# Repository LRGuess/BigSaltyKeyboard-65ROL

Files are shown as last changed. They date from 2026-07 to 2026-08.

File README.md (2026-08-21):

# BigSaltyKeyboard-65ROL
A 65% Keyboard with a rotary encoder, OLED screen and LEDs

## BOM:

- 1x Raspberry Pi Pico
- 68x Cheery MX Switches and their keycaps
- 68x [1N4148 Through-Hole Diodes](https://www.digikey.ca/en/products/detail/onsemi/1N4148/458603)
- 1x 6.25u Stabilizer
- 2x 2.25u Stabilizer
- 1x 2u Stabilizer
- 68x [SK6812 MINI-E LEDs](https://www.lcsc.com/product-detail/C5149201.html)
- 1x [Logic Level Shifter](https://www.digikey.ca/en/products/detail/texas-instruments/SN74AHCT1G125DBVR/376028)
- 69x [0.1 µF Chip Capacitor](https://www.digikey.ca/en/products/detail/samsung-electro-mechanics/CL05B104KP5VPNC/20498482)
- 1x [500 OHM Chip Resistor](https://www.digikey.ca/en/products/detail/yageo/RT0603BRC07500RL/7708292)
- 2x [10 Pin Horizontal Header](https://www.digikey.ca/en/products/detail/w%C3%BCrth-elektronik/61301011021/2508443)

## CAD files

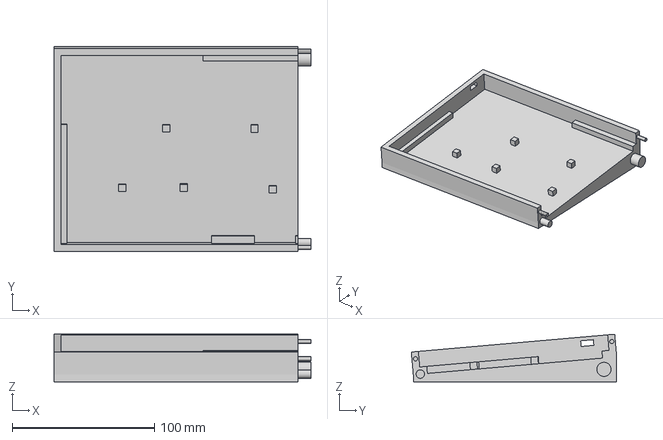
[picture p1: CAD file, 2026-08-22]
Case/CaseLeft.3mf
180.9 x 144.6 x 33.5 mm

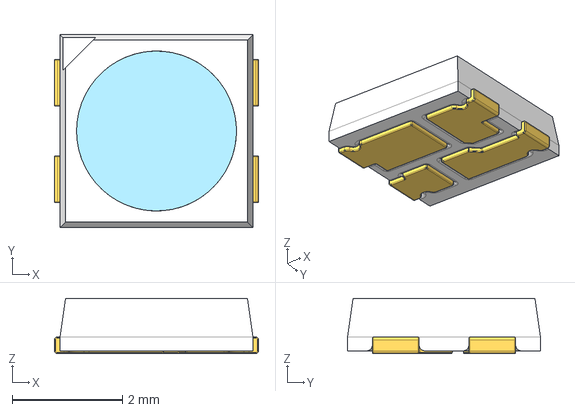
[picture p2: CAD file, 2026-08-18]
PCB/KeyboardPCB/Assets/3D Models/WS2812B Mini.stp
3.70 x 3.50 x 1.00 mm

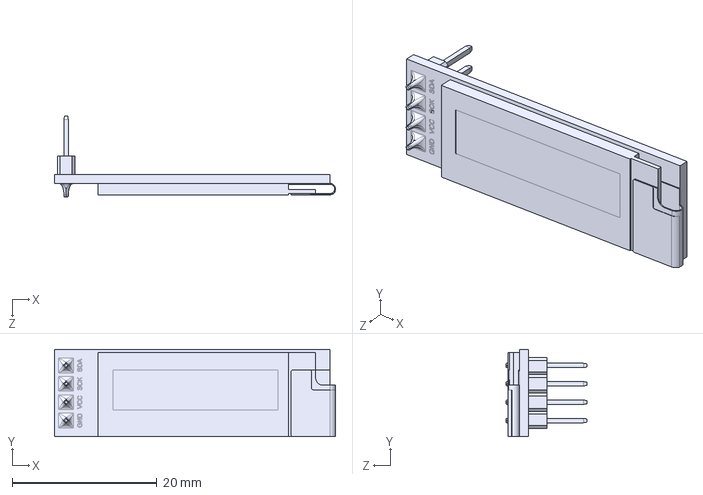
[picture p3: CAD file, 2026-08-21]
PCB/RearExtensionPCB/Assets/3D Models/OLED Screen.STEP
38.8 x 12.1 x 11.2 mm

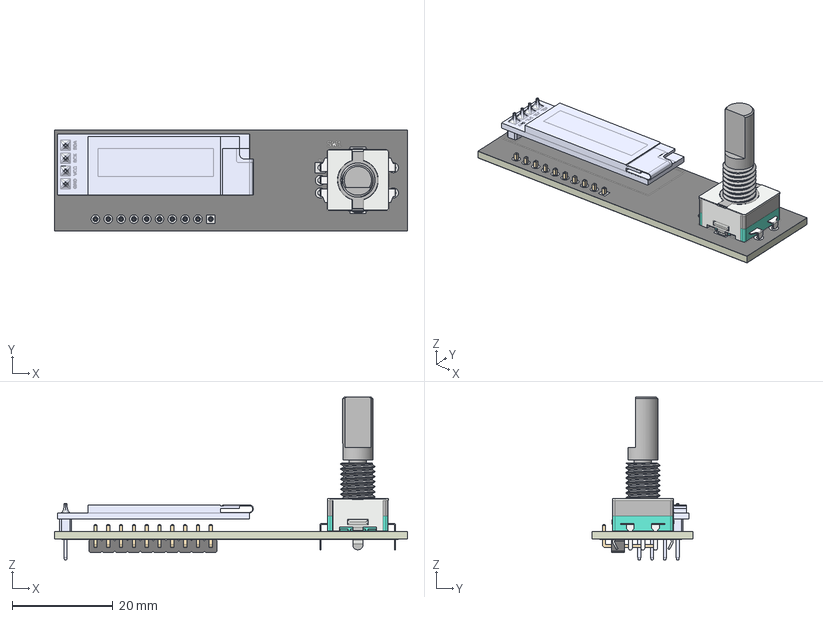
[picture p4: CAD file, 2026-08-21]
PCB/RearExtensionPCB/RearExtensionPCB.step
70.0 x 20.0 x 32.3 mm
EC11 v3
0.91in OLED
PinHeader_1x10_P254mm_Horizontal
RearExtensionPCB_copper
RearExtensionPCB_pad
RearExtensionPCB_via
RearExtensionPCB_silkscreen x 2
RearExtensionPCB_soldermask x 2
RearExtensionPCB_PCB

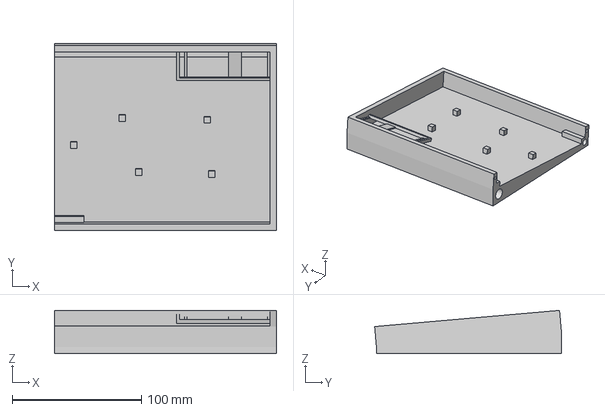
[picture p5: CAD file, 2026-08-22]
Case/CaseRight.3mf
171.9 x 144.6 x 33.5 mm

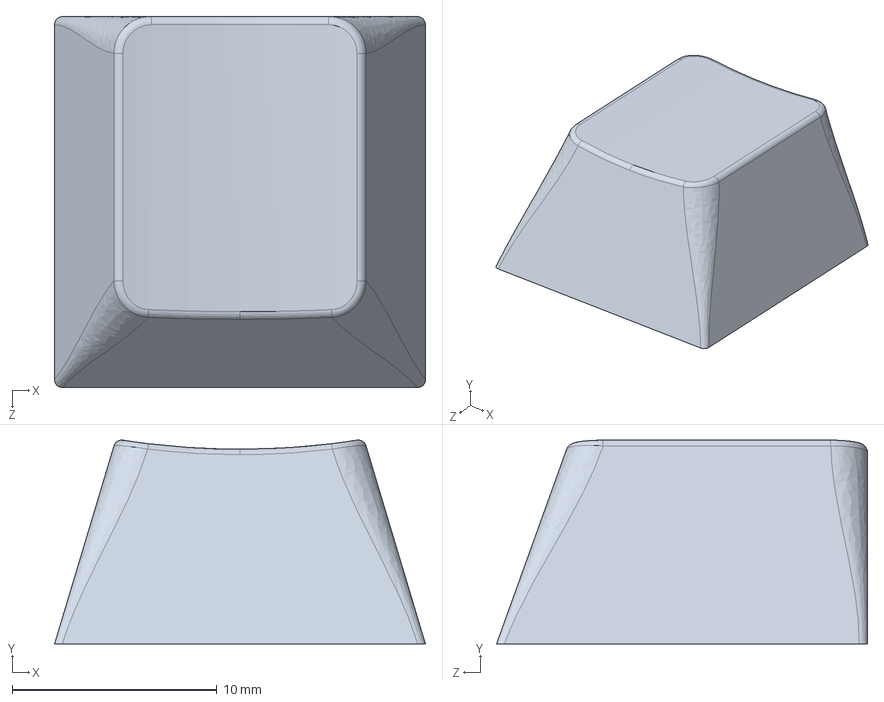
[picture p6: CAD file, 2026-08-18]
PCB/KeyboardPCB/Assets/3D Models/Keycap.STEP
18.1 x 9.95 x 18.1 mm

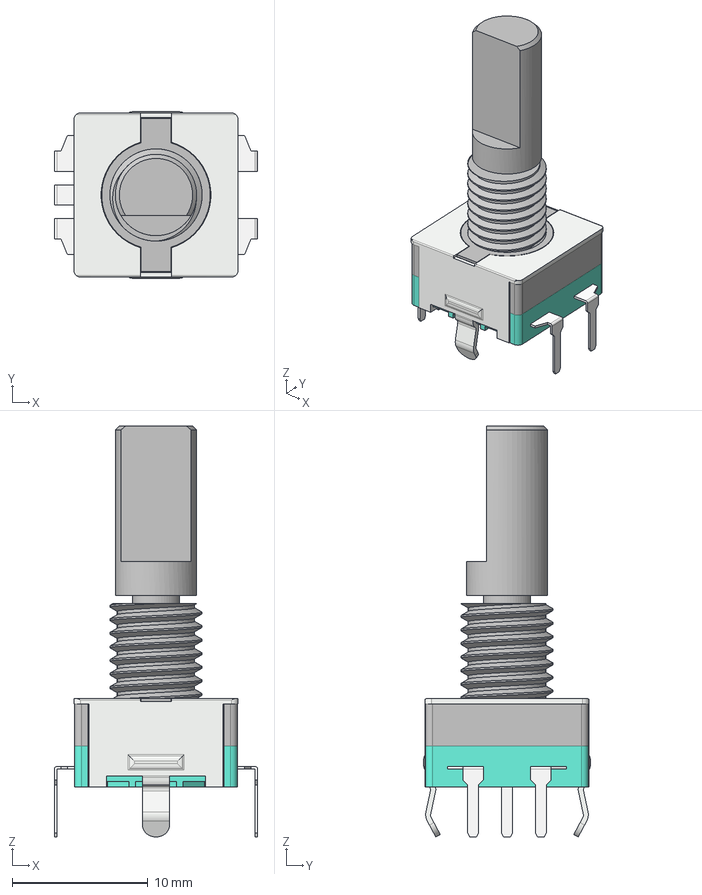
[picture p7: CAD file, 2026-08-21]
PCB/RearExtensionPCB/Assets/3D Models/Rotary Encoder.step
15.0 x 12.3 x 30.3 mm

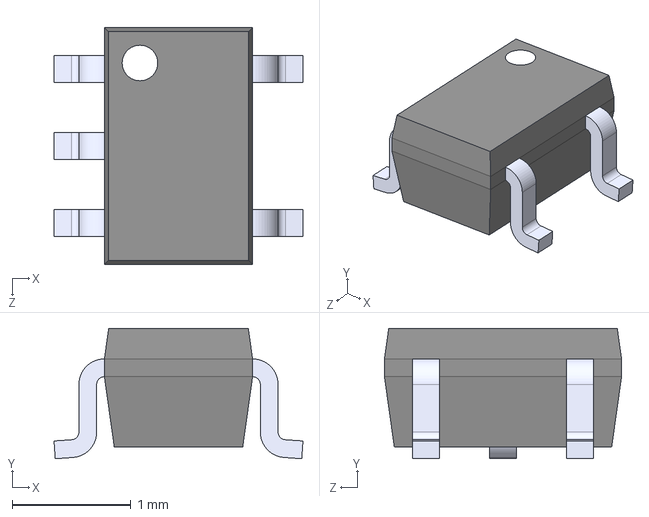
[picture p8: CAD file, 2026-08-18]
PCB/KeyboardPCB/Assets/3D Models/SN74AHCT1G125DCKT.step
2.10 x 1.10 x 2.00 mm

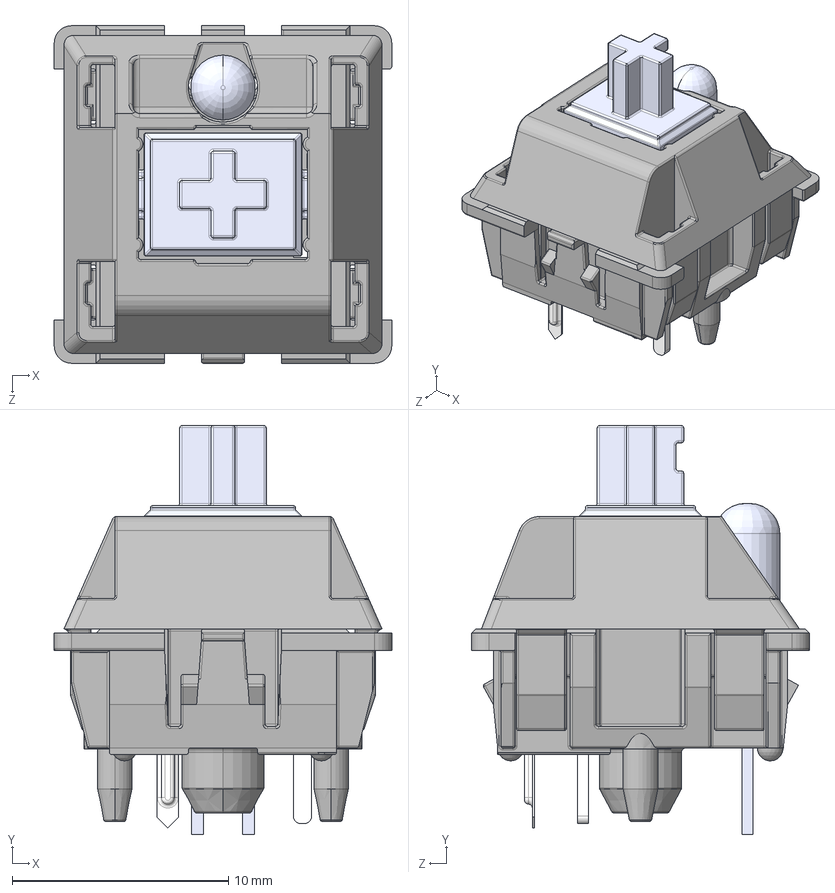
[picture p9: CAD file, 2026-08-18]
PCB/KeyboardPCB/Assets/3D Models/MX_Switch.STEP
15.6 x 18.9 x 15.6 mm
MX 轴 按键′_ü___¨1
MX 轴 轴体áì_¨￠¨__
MX粣 拸簽LEDLEDLED
MX轴 轴体 底部 μ×2__默认_á2____è_
针脚___默认__è_

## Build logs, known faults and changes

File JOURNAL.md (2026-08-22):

## Journal
You can visit the `./Photos` folder to find pictures related to each devlog!  
### Jul 25, Devlog 1: 3 hours
Behold, the start of the project!
I do not have much experiance making keyboards but have been thinking of building one for a lil bit now, and once I came across Keeb it seemed like a great opportunity!  
I kicked this project off with a bit of planning and I present to you the overview of my custom keyboard:  
- Main Board:  
The BigSaltyKeyboard will be a 65% keyboard, meaning it will contain the primary keys + the 4 arrow keys + 4 nav keys: Del, Ins, Pup, and Pdn. I chose this layout as I really enjoy the smallness of 60%s but I certain games I play require the use of the arrows and being able to use the nav keys really helps typing flow. 
The keys will also be a bit offset from each other in the standard way most keyboards do simply for the ergonomics.

- Extra Spice:  
My keyboard will have a few hardware and software features that bring it's uniquness to life! First of all every key will have an SK6812 Mini-E LED under it to add some flare and animations! The top of the keybaord will have a small panel extending upwards containing some cool extra features, mainly a 0.91in programmable OLED screen and a rotary encoder that will be dedicated to volume control! It will also contain some small buttons that can br programmed to do whatever you please!

PCB Design:  
I begun the project by starting the schematic for the PCB in KiCad! For now all I have are ~68 keys connected to diodes for the key matrix and labeled onto the Pico! Due to the nature of the project it will need 2 PCB's, one for the board and another for the extended top, but for now ill work only on the board. 

Next Up:
1. Link footprints and but together PCB with keys
2. LEDs

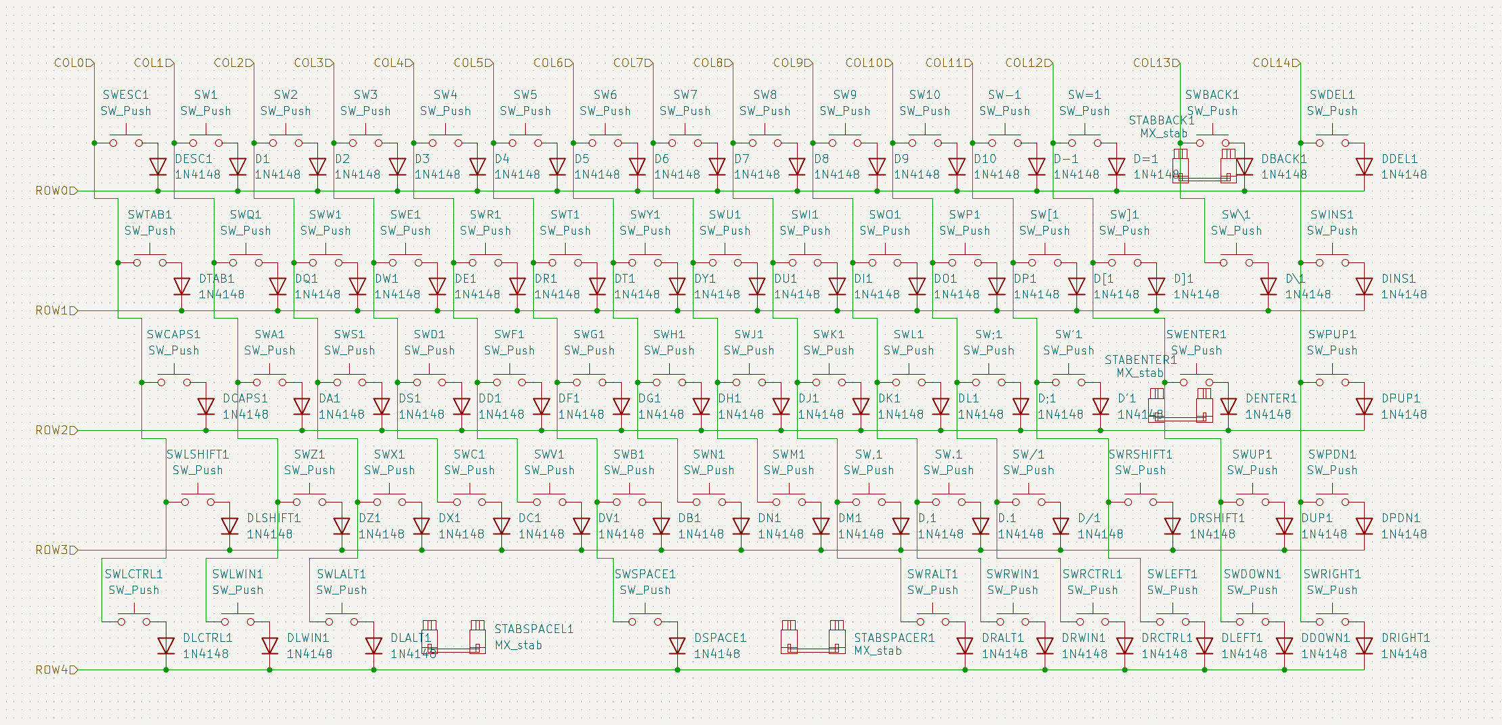
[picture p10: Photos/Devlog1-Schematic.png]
Devlog1 Image
 

### Jul 26, Devlog 2: 3 hours
After having finished the key's schematic layout for the base PCB I dedcided the next step was to lay the keys out on the PCB! My current keyboard is an ATK RS6, and I'm quite used to it's layout and spacing so I decided I would replicate it with a small tweak: I made the left control key just a little bit larger so that I don't have to extend my thumb as far as I do on my current one. Honestly, spacing the keys out was kinda hard but it was a great learning opportunity, and figuring out how to place the stabalizers was also fun to figure out.  
Something I did to help figure the proper spacing out was downloading the CAD for an MX key and a keycap for the switch footprint so I could visualize the spacing in the 3D tool! At first I got the switch CAD to import no problem, but as soon as I tried to import the keycap it wouldn't show up. Long story short, for some ungodly reason KiCAD didn't like the keycap's CAD to be in an STL format but after a conversion to STP everything went smoothly. 

Next Up:
1. Place diodes, Pico, and define board edge.
2. LEDs

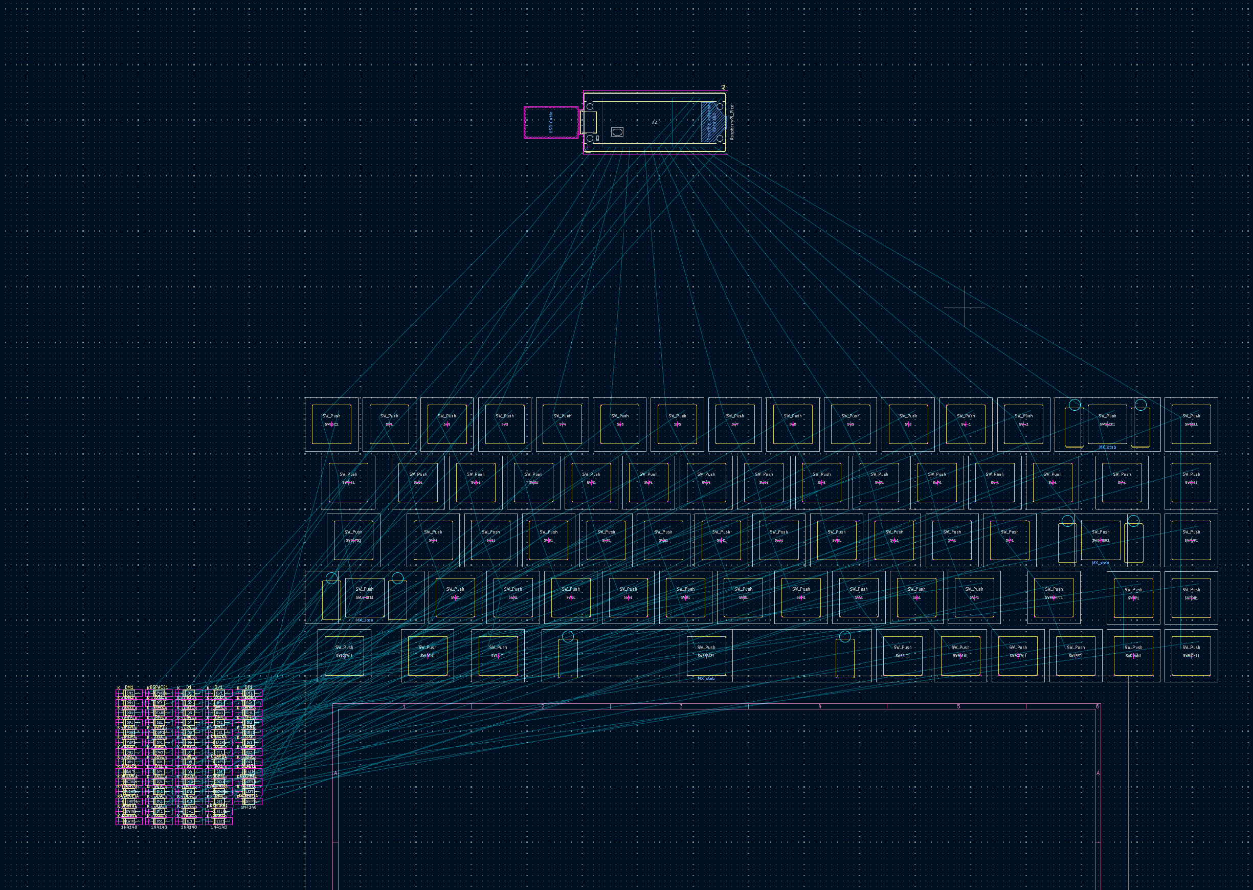
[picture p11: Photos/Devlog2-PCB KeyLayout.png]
Devlog2 Image
 

### Jul 26, Devlog 3: 4 hours
Right off the bat this part took a lot longer than I thought it would. Manually trying to drag every single diode to the right position was an absolute nightmare they're so small it's literally aim trainging of some sorts. Holy cow. 
Anyways, after placing every diode I decided to place the Pico right above the entire structure. Yes this adds a lot of space but that space will be right under the extention and I do need a spot to place the connectors to the other PDB. I'll get into that more in the next devlog.
The last thing I did was define the board's outlines and add a ground fill. I'm leaving about 2.4mm of space between the edge of the board and the switches, which I think will be enough for a sandwitch fit case. Running the DRC nothing failed so all is well with the board for now!

Next Up:
1. LEDs
2. Plan 2nd board connection

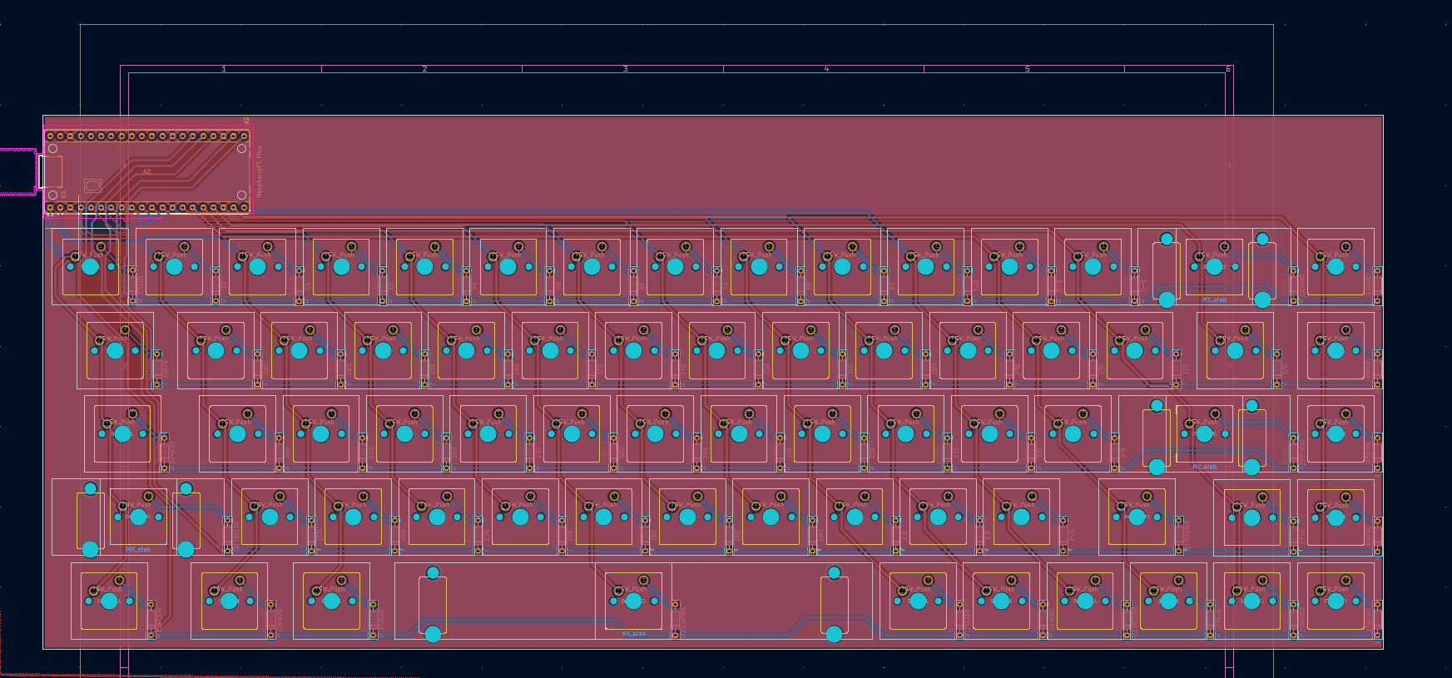
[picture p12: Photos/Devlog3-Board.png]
Devlog3 Image
 

### Aug 4, Devlog 4: 7 hours
Oh boy this one was fun. I really want my keyboard to have LEDs under each key, overall I think it adds a lot of character and improves the overall look of the board. Also they're lowkey aura.  
First thing's first I created a schematic in KiCad and mapped out the routes the data lines were going to take. To make routing a lot easier, I decided that every 2nd row of LEDs are going to be turned upside down, making the data line not have to cross the entire board to start a new row of LEDs. This bit was easy enough and after assigning all the footprints I got to work routing. Now I have routed LEDs in the past, and the process of placing the LEDs got a bit repetitive, so we'll skip to the start of the problems.  
After I finished routing the LEDs I tried to preform a DRC. For some ungodly reason 9/10 times I tried KiCad would crash, never giving me the results. Now I can't really skip over this because there is no way I made a perfect board, so for a few hours it was literally just brute forcing KiCad until it decided to give me the DRC results. At the end of the day it was not too bad as all I had to do was add some vias to allow all the ground fill islands to connect to each other and provide thermal relief. 

Next Up:
1. Create 2nd Schematic for rear extention
2. Figure out how to connect the 2nd PCB to the Pico

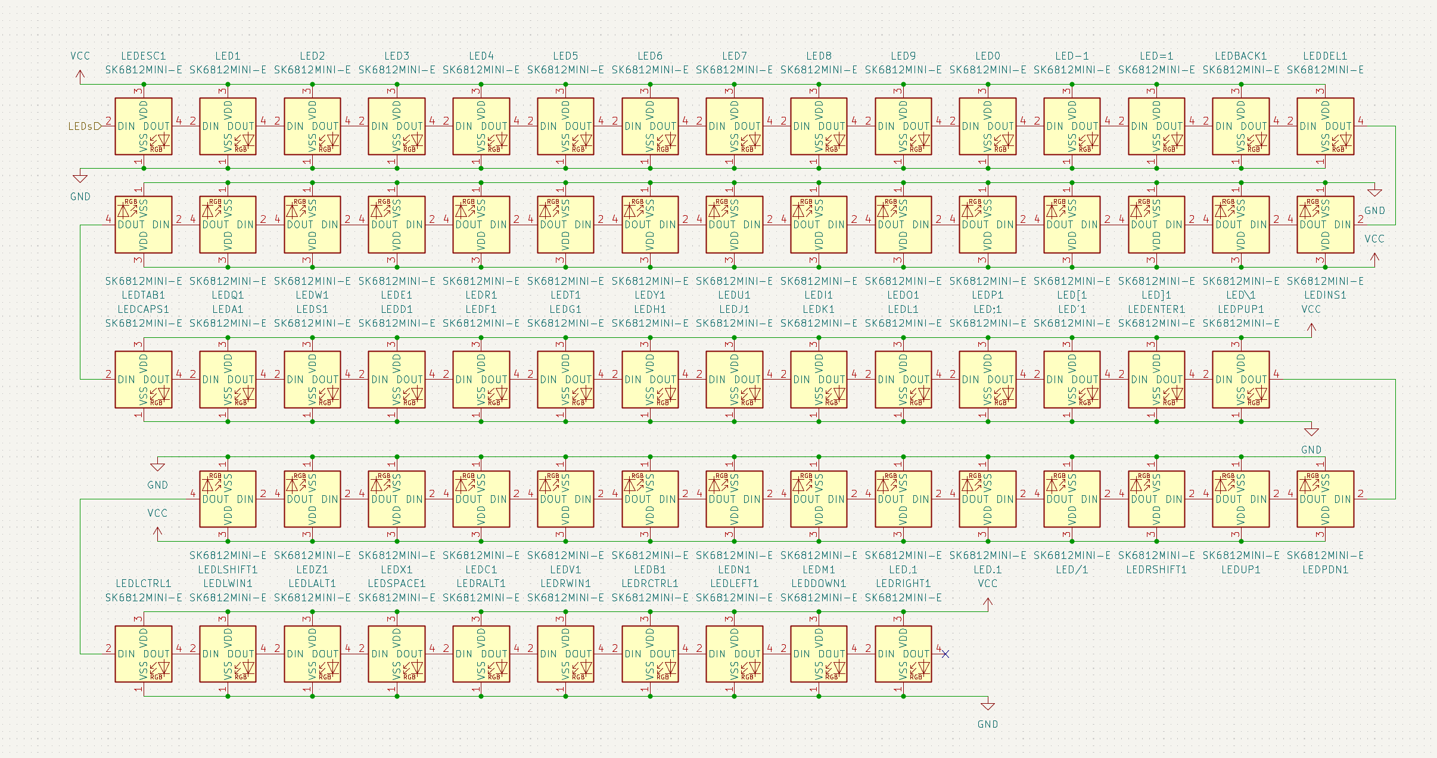
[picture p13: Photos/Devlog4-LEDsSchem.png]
Devlog4 Image
 
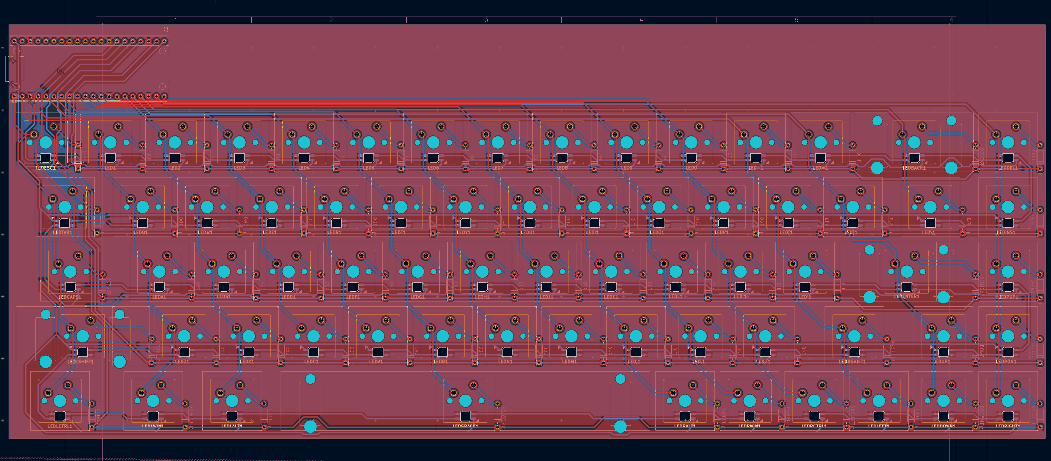
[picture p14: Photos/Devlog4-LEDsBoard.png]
Devlog4 Image
 

### Aug 15, Devlog 5: 2 Hours
I recently shared my keyboard design with the community, and I got a few comments about the LEDs. There were a few changes I needed to make to ensure the LEDs would work properly:
1. Every LED needs a decoupling capacitor to prevent high frequency noise from messing with the LEDs.
2. The LEDs data lines read HIGH from a 5v pin, but the Pico's data lines are 3.3v. Due to this I needed to insert a logic-level shifter between the Pico and the first LED.
3. After the Logic Level shifter it is also recommended to insert a 500OHM resistor on the data line.

After about an hour of research I figured out what components to use and placed them all on the schematic!

Next Up:
1. Place all new components on PCB
2. 2nd PCB

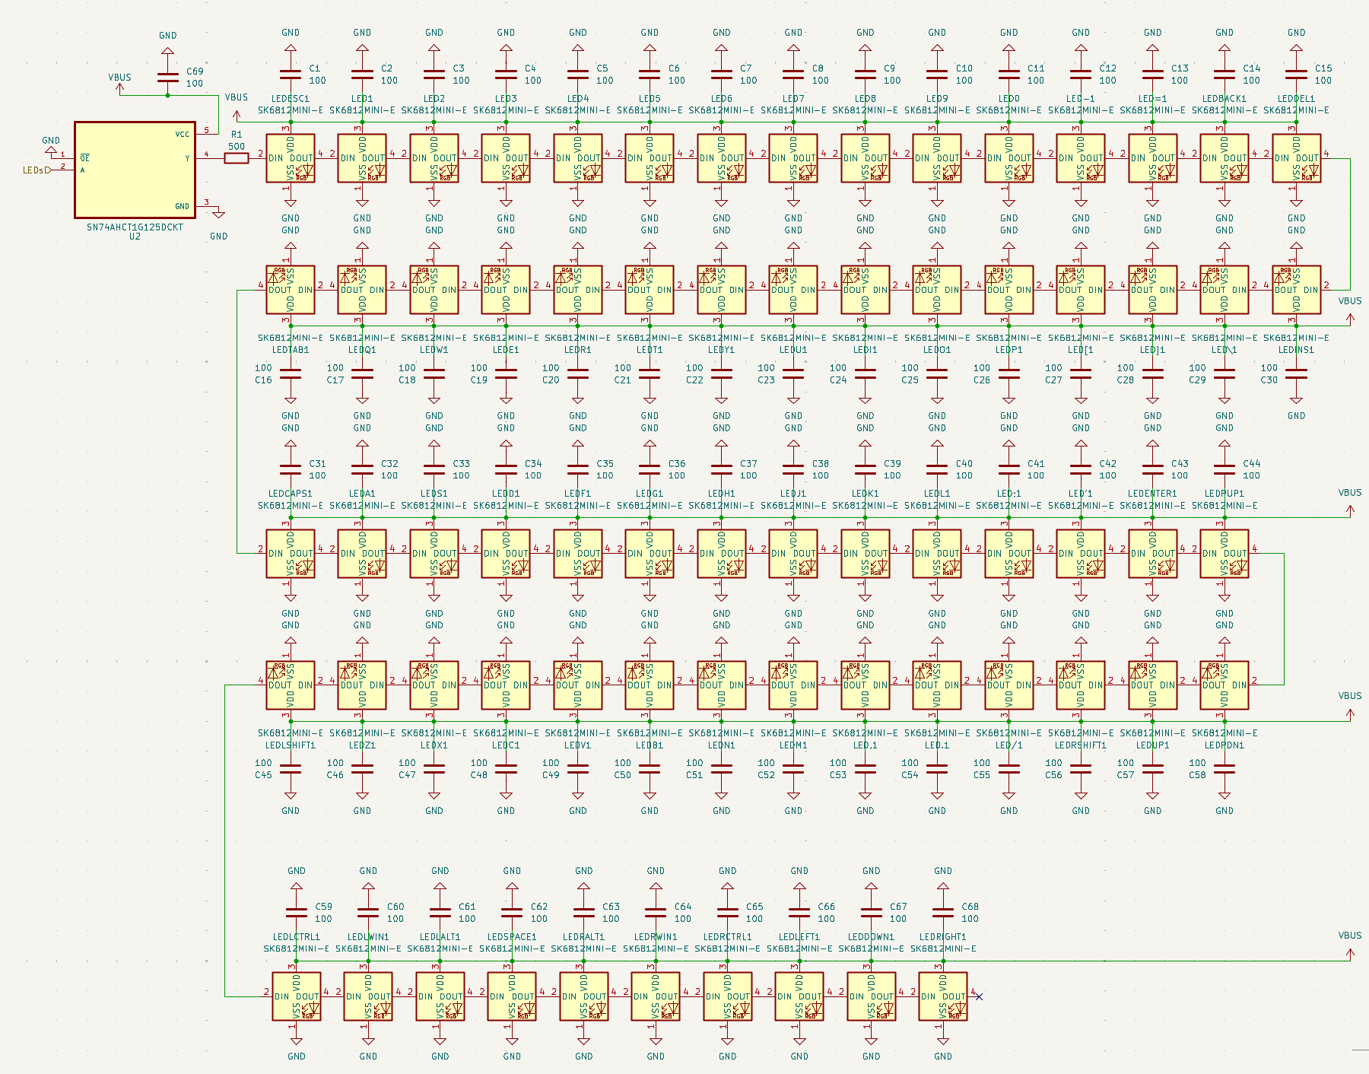
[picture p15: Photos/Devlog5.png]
Devlog5 Image
 

### Aug 17, Devlog 6: 3 Hours
In the previous DevLog I spoke about how I needed to add new components for the LEDs. In this one all I did was place each component on the PCB. This process was quite repetitive and it was a bit hard to figure out how to orient every capacitor to fit nicely, but I figured it out and every capacitor got spaced evenly. The only issue I ran into were isolated GND islands, but I was able to solve that by adding a few dozen vias and allowing all the fill zones to connect to each other!

Next Up:
1. Talk about 2nd PCB
2. Schematic for 2nd PCB
3. Make 2nd PCB

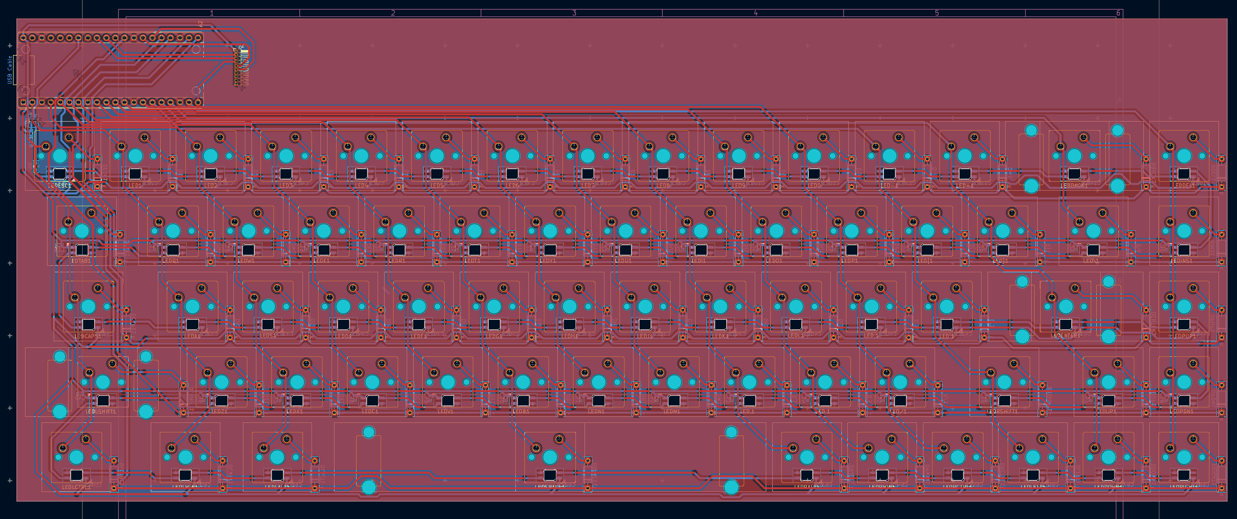
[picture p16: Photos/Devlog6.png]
Devlog6 Image
 

### Aug 17, Devlog 7: 2 Hours
The biggest detail about this keyboard is the rear extension that will come up on the back. I want this extension to have the following details:
1. A Rotary Encoder sticking out the side for volume control
2. OLED screen for funny graphics

In theory I would like to have more features but I have very little ports left on the Pico, and I don't mind missing out on a few buttons. 
To connect each PCB to the other I will simply put a 10 Pin header on each PCB and run jumper wires! I finished the simple schematic for the 2nd PCB, next I need to figure out how to design a 2nd PCB in KiCAD!

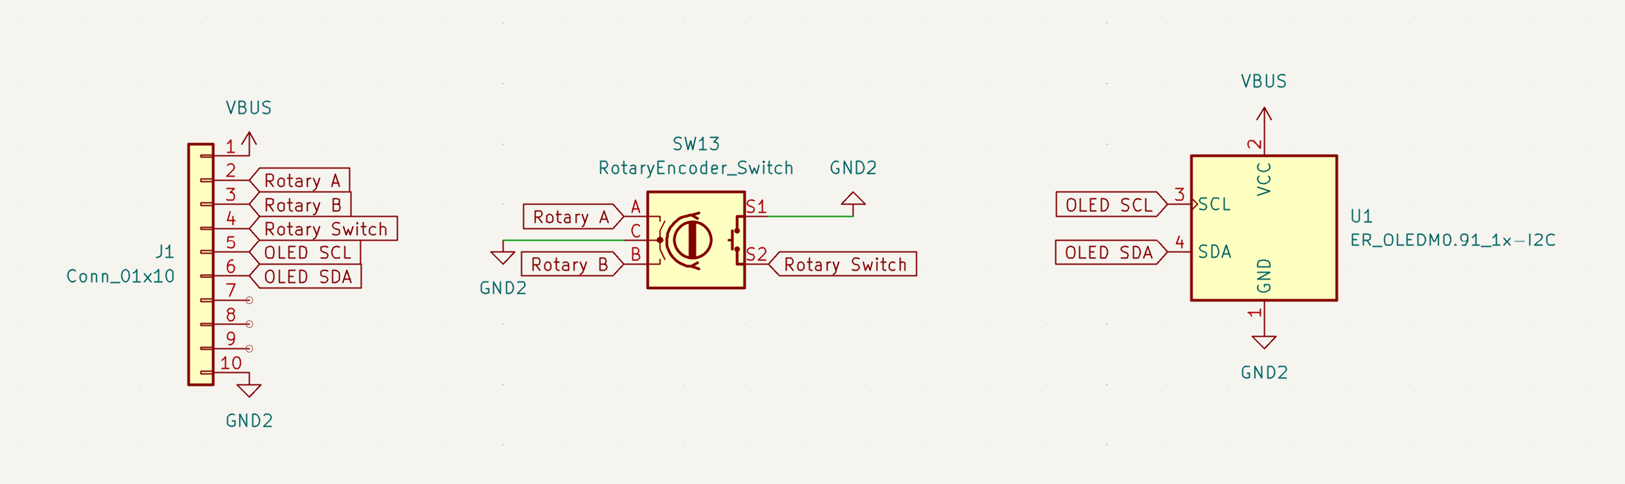
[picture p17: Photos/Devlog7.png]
Devlog7 Image
 

### Aug 20th, Devlog 8: 1 Hour
Today I routed the PCB for the Rear Extension and imported 3D models to later import it into Fusion 360 for case design. To make the design simpler I made the front fill zone take charge of the VBUS net and the rear one be the ground zone. 
That's all for today, See you guys tomorrow!

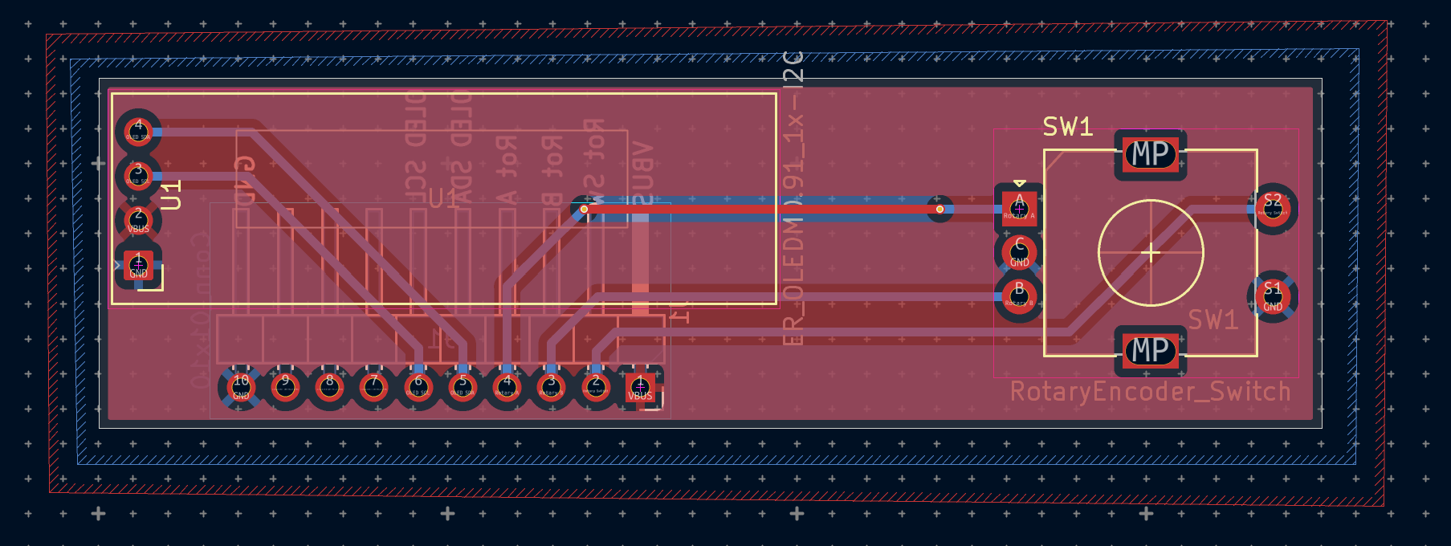
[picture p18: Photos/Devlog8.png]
Devlog8 Image
 

### Aug 21st, Devlog 9: 2 Hours
The last big step of this project is designing the case. I want the case to not be too big but still assert it's presence. The top is left open to see the PCB underneath and any cool designs to be added! I'm already quite familiar with modeling in Fusion so this part was a breeze. The main challenge I encountered when designing the case was the need to split it in half as one piece would be too large to fit on a standard print bed. I solved this by giving one side of the case pegs and the other slot holes, so in theory it should fit together nicely!

Next up are just simple changes and fixes to current design, but for now the keyboard is ready for submission!

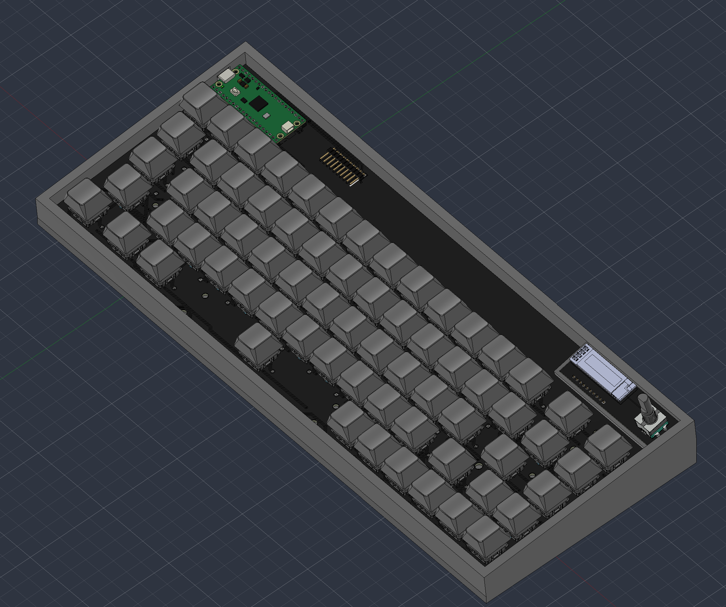
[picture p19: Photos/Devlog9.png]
Devlo9 Image


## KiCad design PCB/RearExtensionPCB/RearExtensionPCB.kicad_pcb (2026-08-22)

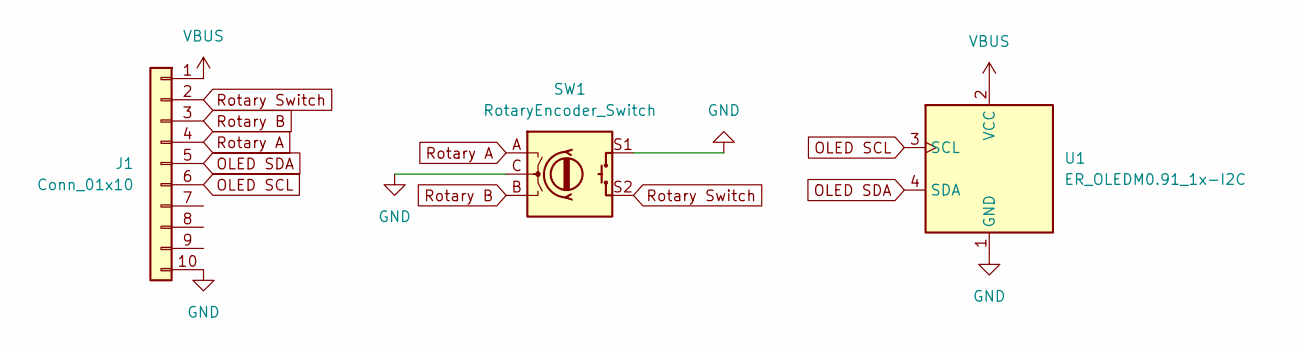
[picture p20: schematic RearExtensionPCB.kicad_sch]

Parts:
J1: Conn_01x10; PinHeader_1x10_P2.54mm_Horizontal
SW1: RotaryEncoder_Switch; RotaryEncoder_Alps_EC11E-Switch_Vertical_H20mm
U1: ER_OLEDM0.91_1x-I2C

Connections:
GND: J1.10, SW1.C, SW1.S1, U1.1 (GND)
OLED SCL: J1.6, U1.3 (SCL)
OLED SDA: J1.5, U1.4 (SDA)
Rotary A: J1.4, SW1.A
Rotary B: J1.3, SW1.B
Rotary Switch: J1.2, SW1.S2
VBUS: J1.1, U1.2 (VCC)

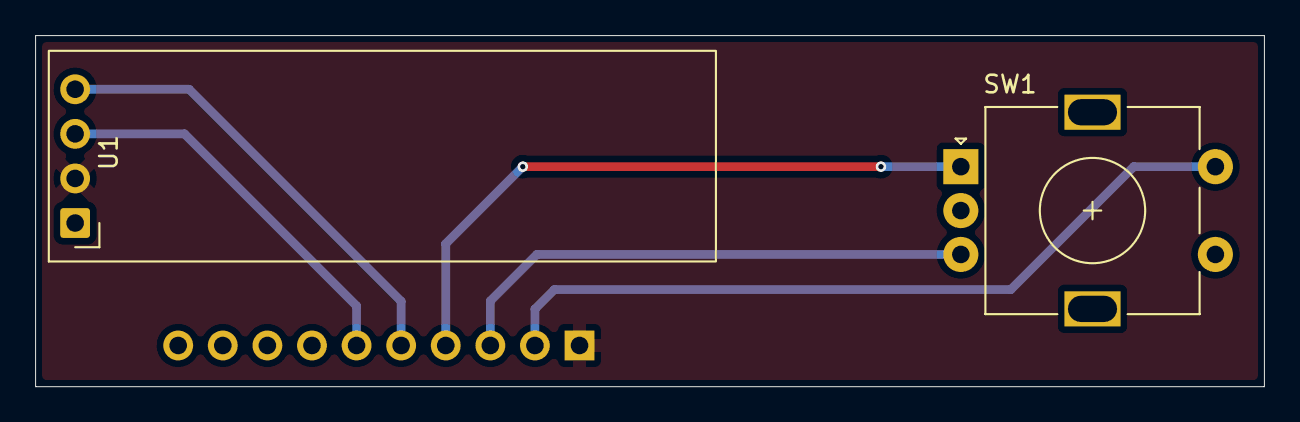
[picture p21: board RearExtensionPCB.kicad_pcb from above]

Board: 2 copper layers, 70.0 x 20.0 mm, 3 parts (1 on the bottom side), 7 nets.

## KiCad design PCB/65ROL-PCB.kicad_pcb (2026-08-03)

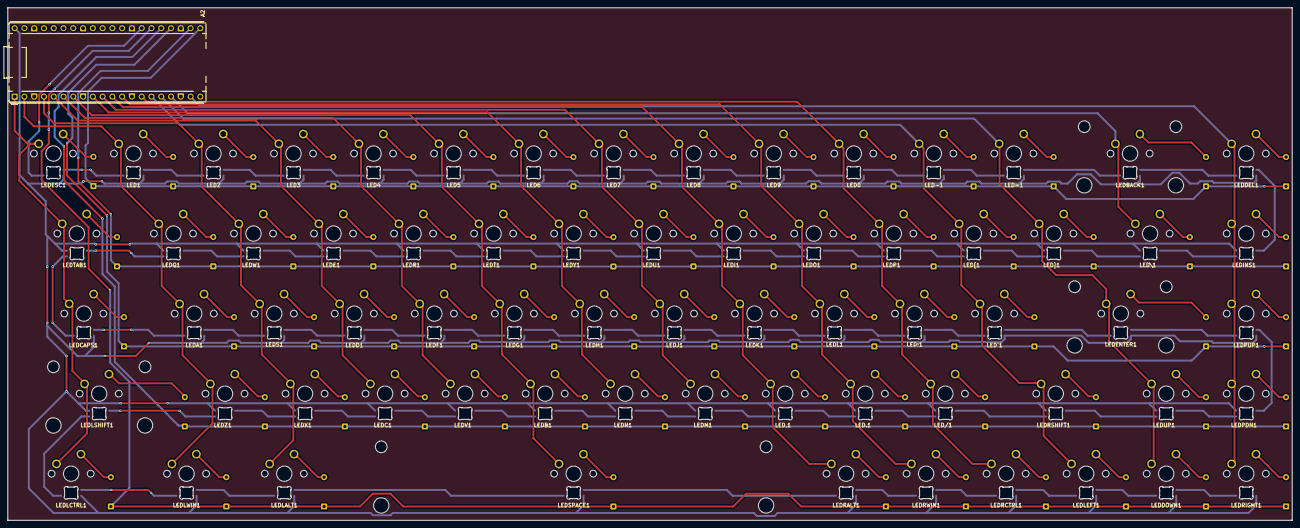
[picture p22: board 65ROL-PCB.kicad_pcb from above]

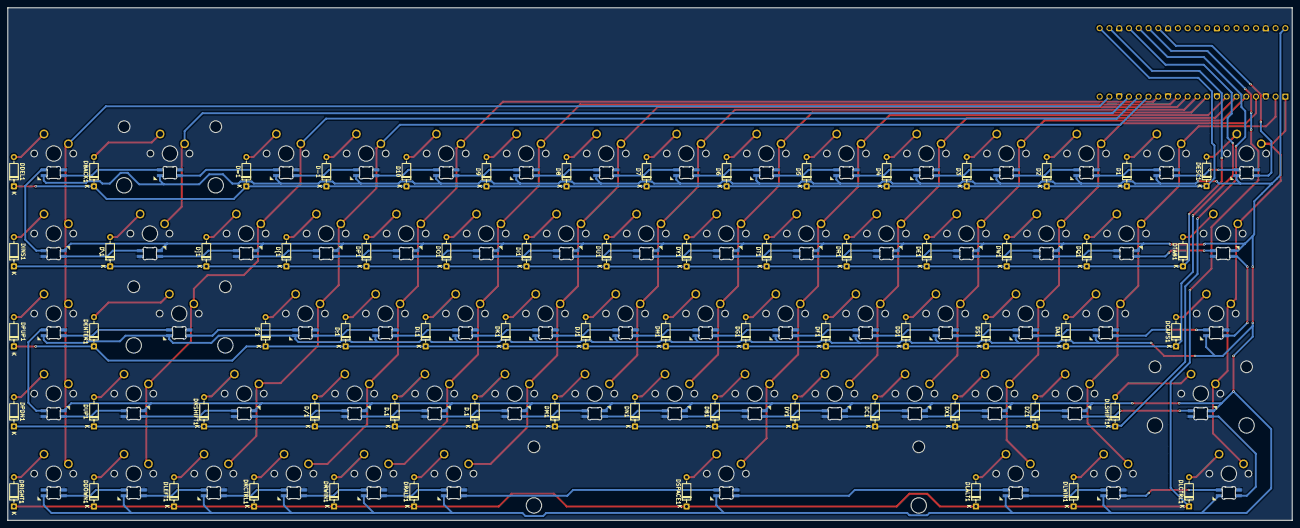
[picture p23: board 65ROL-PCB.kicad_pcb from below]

Board: 2 copper layers, 333.8 x 133.2 mm, 209 parts (68 on the bottom side), 158 nets.

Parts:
A2: RaspberryPi_Pico; RaspberryPi_Pico_Common_THT
D1, D2, D3, D4, D5, D6, D7, D8, D9, D10, D.1: 1N4148; D_DO-35_SOD27_P7.62mm_Horizontal
D'1: 1N4148; D_DO-35_SOD27_P7.62mm_Horizontal
D,1: 1N4148; D_DO-35_SOD27_P7.62mm_Horizontal
D-1: 1N4148; D_DO-35_SOD27_P7.62mm_Horizontal
D/1: 1N4148; D_DO-35_SOD27_P7.62mm_Horizontal
D;1: 1N4148; D_DO-35_SOD27_P7.62mm_Horizontal
D=1: 1N4148; D_DO-35_SOD27_P7.62mm_Horizontal
DA1: 1N4148; D_DO-35_SOD27_P7.62mm_Horizontal
DB1: 1N4148; D_DO-35_SOD27_P7.62mm_Horizontal
DBACK1: 1N4148; D_DO-35_SOD27_P7.62mm_Horizontal
DC1: 1N4148; D_DO-35_SOD27_P7.62mm_Horizontal
DCAPS1: 1N4148; D_DO-35_SOD27_P7.62mm_Horizontal
DD1: 1N4148; D_DO-35_SOD27_P7.62mm_Horizontal
DDEL1: 1N4148; D_DO-35_SOD27_P7.62mm_Horizontal
DDOWN1: 1N4148; D_DO-35_SOD27_P7.62mm_Horizontal
DE1: 1N4148; D_DO-35_SOD27_P7.62mm_Horizontal
DENTER1: 1N4148; D_DO-35_SOD27_P7.62mm_Horizontal
DESC1: 1N4148; D_DO-35_SOD27_P7.62mm_Horizontal
DF1: 1N4148; D_DO-35_SOD27_P7.62mm_Horizontal
DG1: 1N4148; D_DO-35_SOD27_P7.62mm_Horizontal
DH1: 1N4148; D_DO-35_SOD27_P7.62mm_Horizontal
DI1: 1N4148; D_DO-35_SOD27_P7.62mm_Horizontal
DINS1: 1N4148; D_DO-35_SOD27_P7.62mm_Horizontal
DJ1: 1N4148; D_DO-35_SOD27_P7.62mm_Horizontal
DK1: 1N4148; D_DO-35_SOD27_P7.62mm_Horizontal
DL1: 1N4148; D_DO-35_SOD27_P7.62mm_Horizontal
DLALT1: 1N4148; D_DO-35_SOD27_P7.62mm_Horizontal
DLCTRL1: 1N4148; D_DO-35_SOD27_P7.62mm_Horizontal
DLEFT1: 1N4148; D_DO-35_SOD27_P7.62mm_Horizontal
DLSHIFT1: 1N4148; D_DO-35_SOD27_P7.62mm_Horizontal
DLWIN1: 1N4148; D_DO-35_SOD27_P7.62mm_Horizontal
DM1: 1N4148; D_DO-35_SOD27_P7.62mm_Horizontal
DN1: 1N4148; D_DO-35_SOD27_P7.62mm_Horizontal
DO1: 1N4148; D_DO-35_SOD27_P7.62mm_Horizontal
DP1: 1N4148; D_DO-35_SOD27_P7.62mm_Horizontal
DPDN1: 1N4148; D_DO-35_SOD27_P7.62mm_Horizontal
DPUP1: 1N4148; D_DO-35_SOD27_P7.62mm_Horizontal
DQ1: 1N4148; D_DO-35_SOD27_P7.62mm_Horizontal
DR1: 1N4148; D_DO-35_SOD27_P7.62mm_Horizontal
DRALT1: 1N4148; D_DO-35_SOD27_P7.62mm_Horizontal
DRCTRL1: 1N4148; D_DO-35_SOD27_P7.62mm_Horizontal
DRIGHT1: 1N4148; D_DO-35_SOD27_P7.62mm_Horizontal
DRSHIFT1: 1N4148; D_DO-35_SOD27_P7.62mm_Horizontal
DRWIN1: 1N4148; D_DO-35_SOD27_P7.62mm_Horizontal
DS1: 1N4148; D_DO-35_SOD27_P7.62mm_Horizontal
DSPACE1: 1N4148; D_DO-35_SOD27_P7.62mm_Horizontal
DT1: 1N4148; D_DO-35_SOD27_P7.62mm_Horizontal
DTAB1: 1N4148; D_DO-35_SOD27_P7.62mm_Horizontal
DU1: 1N4148; D_DO-35_SOD27_P7.62mm_Horizontal
DUP1: 1N4148; D_DO-35_SOD27_P7.62mm_Horizontal
DV1: 1N4148; D_DO-35_SOD27_P7.62mm_Horizontal
DW1: 1N4148; D_DO-35_SOD27_P7.62mm_Horizontal
DX1: 1N4148; D_DO-35_SOD27_P7.62mm_Horizontal
DY1: 1N4148; D_DO-35_SOD27_P7.62mm_Horizontal
DZ1: 1N4148; D_DO-35_SOD27_P7.62mm_Horizontal
D[1: 1N4148; D_DO-35_SOD27_P7.62mm_Horizontal
D\1: 1N4148; D_DO-35_SOD27_P7.62mm_Horizontal
D]1: 1N4148; D_DO-35_SOD27_P7.62mm_Horizontal
LED0, LED1, LED2, LED3, LED4, LED5, LED6, LED7, LED8, LED9, LED.1: SK6812MINI-E; SK6812MINI-E_fixed
LED'1: SK6812MINI-E; SK6812MINI-E_fixed
LED,1: SK6812MINI-E; SK6812MINI-E_fixed
LED-1: SK6812MINI-E; SK6812MINI-E_fixed
LED/1: SK6812MINI-E; SK6812MINI-E_fixed
LED;1: SK6812MINI-E; SK6812MINI-E_fixed
LED=1: SK6812MINI-E; SK6812MINI-E_fixed
LEDA1: SK6812MINI-E; SK6812MINI-E_fixed
LEDB1: SK6812MINI-E; SK6812MINI-E_fixed
LEDBACK1: SK6812MINI-E; SK6812MINI-E_fixed
LEDC1: SK6812MINI-E; SK6812MINI-E_fixed
LEDCAPS1: SK6812MINI-E; SK6812MINI-E_fixed
LEDD1: SK6812MINI-E; SK6812MINI-E_fixed
LEDDEL1: SK6812MINI-E; SK6812MINI-E_fixed
LEDDOWN1: SK6812MINI-E; SK6812MINI-E_fixed
LEDE1: SK6812MINI-E; SK6812MINI-E_fixed
LEDENTER1: SK6812MINI-E; SK6812MINI-E_fixed
LEDESC1: SK6812MINI-E; SK6812MINI-E_fixed
LEDF1: SK6812MINI-E; SK6812MINI-E_fixed
LEDG1: SK6812MINI-E; SK6812MINI-E_fixed
LEDH1: SK6812MINI-E; SK6812MINI-E_fixed
LEDI1: SK6812MINI-E; SK6812MINI-E_fixed
LEDINS1: SK6812MINI-E; SK6812MINI-E_fixed
LEDJ1: SK6812MINI-E; SK6812MINI-E_fixed
LEDK1: SK6812MINI-E; SK6812MINI-E_fixed
LEDL1: SK6812MINI-E; SK6812MINI-E_fixed
LEDLALT1: SK6812MINI-E; SK6812MINI-E_fixed
LEDLCTRL1: SK6812MINI-E; SK6812MINI-E_fixed
LEDLEFT1: SK6812MINI-E; SK6812MINI-E_fixed
LEDLSHIFT1: SK6812MINI-E; SK6812MINI-E_fixed
LEDLWIN1: SK6812MINI-E; SK6812MINI-E_fixed
LEDM1: SK6812MINI-E; SK6812MINI-E_fixed
LEDN1: SK6812MINI-E; SK6812MINI-E_fixed
LEDO1: SK6812MINI-E; SK6812MINI-E_fixed
LEDP1: SK6812MINI-E; SK6812MINI-E_fixed
LEDPDN1: SK6812MINI-E; SK6812MINI-E_fixed
LEDPUP1: SK6812MINI-E; SK6812MINI-E_fixed
LEDQ1: SK6812MINI-E; SK6812MINI-E_fixed
LEDR1: SK6812MINI-E; SK6812MINI-E_fixed
LEDRALT1: SK6812MINI-E; SK6812MINI-E_fixed
LEDRCTRL1: SK6812MINI-E; SK6812MINI-E_fixed
LEDRIGHT1: SK6812MINI-E; SK6812MINI-E_fixed
LEDRSHIFT1: SK6812MINI-E; SK6812MINI-E_fixed
LEDRWIN1: SK6812MINI-E; SK6812MINI-E_fixed
LEDS1: SK6812MINI-E; SK6812MINI-E_fixed
LEDSPACE1: SK6812MINI-E; SK6812MINI-E_fixed
LEDT1: SK6812MINI-E; SK6812MINI-E_fixed
LEDTAB1: SK6812MINI-E; SK6812MINI-E_fixed
LEDU1: SK6812MINI-E; SK6812MINI-E_fixed
LEDUP1: SK6812MINI-E; SK6812MINI-E_fixed
LEDV1: SK6812MINI-E; SK6812MINI-E_fixed
LEDW1: SK6812MINI-E; SK6812MINI-E_fixed
LEDX1: SK6812MINI-E; SK6812MINI-E_fixed
LEDY1: SK6812MINI-E; SK6812MINI-E_fixed
LEDZ1: SK6812MINI-E; SK6812MINI-E_fixed
LED[1: SK6812MINI-E; SK6812MINI-E_fixed
LED\1: SK6812MINI-E; SK6812MINI-E_fixed
LED]1: SK6812MINI-E; SK6812MINI-E_fixed
STABBACK1: MX_stab; STAB_MX_2u
STABENTER1: MX_stab; STAB_MX_2.25u
STABLSHIFT1: MX_stab; STAB_MX_2.25u
STABSPACE1: MX_stab; STAB_MX_6.25u
SW0, SW1, SW2, SW3, SW4, SW5, SW6, SW7, SW8, SW9, SW.1: SW_Push; SW_MX_1u
SW'1: SW_Push; SW_MX_1u
SW,1: SW_Push; SW_MX_1u
SW-1: SW_Push; SW_MX_1u
SW/1: SW_Push; SW_MX_1u
SW;1: SW_Push; SW_MX_1u
SW=1: SW_Push; SW_MX_1u
SWA1: SW_Push; SW_MX_1u
SWB1: SW_Push; SW_MX_1u
SWBACK1: SW_Push; SW_MX_1u
SWC1: SW_Push; SW_MX_1u
SWCAPS1: SW_Push; SW_MX_1u
SWD1: SW_Push; SW_MX_1u
SWDEL1: SW_Push; SW_MX_1u
SWDOWN1: SW_Push; SW_MX_1u
SWE1: SW_Push; SW_MX_1u
SWENTER1: SW_Push; SW_MX_1u
SWESC1: SW_Push; SW_MX_1u
SWF1: SW_Push; SW_MX_1u
SWG1: SW_Push; SW_MX_1u
SWH1: SW_Push; SW_MX_1u
SWI1: SW_Push; SW_MX_1u
SWINS1: SW_Push; SW_MX_1u
SWJ1: SW_Push; SW_MX_1u
SWK1: SW_Push; SW_MX_1u
SWL1: SW_Push; SW_MX_1u
SWLALT1: SW_Push; SW_MX_1u
SWLCTRL1: SW_Push; SW_MX_1u
SWLEFT1: SW_Push; SW_MX_1u
SWLSHIFT1: SW_Push; SW_MX_1u
SWLWIN1: SW_Push; SW_MX_1u
SWM1: SW_Push; SW_MX_1u
SWN1: SW_Push; SW_MX_1u
SWO1: SW_Push; SW_MX_1u
SWP1: SW_Push; SW_MX_1u
SWPDN1: SW_Push; SW_MX_1u
SWPUP1: SW_Push; SW_MX_1u
SWQ1: SW_Push; SW_MX_1u
SWR1: SW_Push; SW_MX_1u
SWRALT1: SW_Push; SW_MX_1u
SWRCTRL1: SW_Push; SW_MX_1u
SWRIGHT1: SW_Push; SW_MX_1u
SWRSHIFT1: SW_Push; SW_MX_1u
SWRWIN1: SW_Push; SW_MX_1u
SWS1: SW_Push; SW_MX_1u
SWSPACE1: SW_Push; SW_MX_1u
SWT1: SW_Push; SW_MX_1u
SWTAB1: SW_Push; SW_MX_1u
SWU1: SW_Push; SW_MX_1u
SWUP1: SW_Push; SW_MX_1u
SWV1: SW_Push; SW_MX_1u
SWW1: SW_Push; SW_MX_1u
SWX1: SW_Push; SW_MX_1u
SWY1: SW_Push; SW_MX_1u
SWZ1: SW_Push; SW_MX_1u
SW[1: SW_Push; SW_MX_1u
SW\1: SW_Push; SW_MX_1u
SW]1: SW_Push; SW_MX_1u

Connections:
/Board Keys/COL0: A2.1 (GPIO0), SWCAPS1.1, SWESC1.1, SWLCTRL1.1, SWLSHIFT1.1, SWTAB1.1
/Board Keys/COL1: A2.2 (GPIO1), SW1.1, SWA1.1, SWLWIN1.1, SWQ1.1, SWZ1.1
/Board Keys/COL2: A2.4 (GPIO2), SW2.1, SWLALT1.1, SWS1.1, SWW1.1, SWX1.1
/Board Keys/COL3: A2.5 (GPIO3), SW3.1, SWC1.1, SWD1.1, SWE1.1
/Board Keys/COL4: A2.6 (GPIO4), SW4.1, SWF1.1, SWR1.1, SWV1.1
/Board Keys/COL5: A2.7 (GPIO5), SW5.1, SWB1.1, SWG1.1, SWSPACE1.1, SWT1.1
/Board Keys/COL6: A2.9 (GPIO6), SW6.1, SWH1.1, SWN1.1, SWY1.1
/Board Keys/COL7: A2.10 (GPIO7), SW7.1, SWJ1.1, SWM1.1, SWU1.1
/Board Keys/COL8: A2.11 (GPIO8), SW8.1, SW,1.1, SWI1.1, SWK1.1, SWRALT1.1
/Board Keys/COL9: A2.12 (GPIO9), SW9.1, SW.1.1, SWL1.1, SWO1.1, SWRWIN1.1
/Board Keys/COL10: A2.14 (GPIO10), SW0.1, SW/1.1, SW;1.1, SWP1.1, SWRCTRL1.1
/Board Keys/COL11: A2.15 (GPIO11), SW'1.1, SW-1.1, SWLEFT1.1, SWRSHIFT1.1, SW[1.1
/Board Keys/COL12: A2.16 (GPIO12), SW=1.1, SWDOWN1.1, SWENTER1.1, SWUP1.1, SW]1.1
/Board Keys/COL13: A2.17 (GPIO13), SWBACK1.1, SW\1.1
/Board Keys/COL14: A2.19 (GPIO14), SWDEL1.1, SWINS1.1, SWPDN1.1, SWPUP1.1, SWRIGHT1.1
/Board LEDs/LEDs: A2.27 (GPIO21), LEDESC1.2 (DIN)
/R0: A2.21 (GPIO16), D1.1 (K), D2.1 (K), D3.1 (K), D4.1 (K), D5.1 (K), D6.1 (K), D7.1 (K), D8.1 (K), D9.1 (K), D10.1 (K), D-1.1 (K), D=1.1 (K), DBACK1.1 (K), DDEL1.1 (K), DESC1.1 (K)
/R1: A2.22 (GPIO17), DE1.1 (K), DI1.1 (K), DINS1.1 (K), DO1.1 (K), DP1.1 (K), DQ1.1 (K), DR1.1 (K), DT1.1 (K), DTAB1.1 (K), DU1.1 (K), DW1.1 (K), DY1.1 (K), D[1.1 (K), D\1.1 (K), D]1.1 (K)
/R2: A2.24 (GPIO18), D'1.1 (K), D;1.1 (K), DA1.1 (K), DCAPS1.1 (K), DD1.1 (K), DENTER1.1 (K), DF1.1 (K), DG1.1 (K), DH1.1 (K), DJ1.1 (K), DK1.1 (K), DL1.1 (K), DPUP1.1 (K), DS1.1 (K)
/R3: A2.25 (GPIO19), D,1.1 (K), D.1.1 (K), D/1.1 (K), DB1.1 (K), DC1.1 (K), DLSHIFT1.1 (K), DM1.1 (K), DN1.1 (K), DPDN1.1 (K), DRSHIFT1.1 (K), DUP1.1 (K), DV1.1 (K), DX1.1 (K), DZ1.1 (K)
/R4: A2.26 (GPIO20), DDOWN1.1 (K), DLALT1.1 (K), DLCTRL1.1 (K), DLEFT1.1 (K), DLWIN1.1 (K), DRALT1.1 (K), DRCTRL1.1 (K), DRIGHT1.1 (K), DRWIN1.1 (K), DSPACE1.1 (K)
GND: A2.3 (GND), A2.8 (GND), A2.13 (GND), A2.18 (GND), A2.23 (GND), A2.28 (GND), A2.38 (GND), LED0.1 (VSS), LED1.1 (VSS), LED2.1 (VSS), LED3.1 (VSS), LED4.1 (VSS), LED5.1 (VSS), LED6.1 (VSS), LED7.1 (VSS), LED8.1 (VSS), LED9.1 (VSS), LED'1.1 (VSS), LED,1.1 (VSS), LED-1.1 (VSS), LED.1.1 (VSS), LED/1.1 (VSS), LED;1.1 (VSS), LED=1.1 (VSS), LEDA1.1 (VSS), LEDB1.1 (VSS), LEDBACK1.1 (VSS), LEDC1.1 (VSS), LEDCAPS1.1 (VSS), LEDD1.1 (VSS), LEDDEL1.1 (VSS), LEDDOWN1.1 (VSS), LEDE1.1 (VSS), LEDENTER1.1 (VSS), LEDESC1.1 (VSS), LEDF1.1 (VSS), LEDG1.1 (VSS), LEDH1.1 (VSS), LEDI1.1 (VSS), LEDINS1.1 (VSS), LEDJ1.1 (VSS), LEDK1.1 (VSS), LEDL1.1 (VSS), LEDLALT1.1 (VSS), LEDLCTRL1.1 (VSS), LEDLEFT1.1 (VSS), LEDLSHIFT1.1 (VSS), LEDLWIN1.1 (VSS), LEDM1.1 (VSS), LEDN1.1 (VSS), LEDO1.1 (VSS), LEDP1.1 (VSS), LEDPDN1.1 (VSS), LEDPUP1.1 (VSS), LEDQ1.1 (VSS), LEDR1.1 (VSS), LEDRALT1.1 (VSS), LEDRCTRL1.1 (VSS), LEDRIGHT1.1 (VSS), LEDRSHIFT1.1 (VSS), LEDRWIN1.1 (VSS), LEDS1.1 (VSS), LEDSPACE1.1 (VSS), LEDT1.1 (VSS), LEDTAB1.1 (VSS), LEDU1.1 (VSS), LEDUP1.1 (VSS), LEDV1.1 (VSS), LEDW1.1 (VSS), LEDX1.1 (VSS), LEDY1.1 (VSS), LEDZ1.1 (VSS), LED[1.1 (VSS), LED\1.1 (VSS), LED]1.1 (VSS)
unnamed: D1.2 (A), SW1.2
unnamed: D2.2 (A), SW2.2
unnamed: D3.2 (A), SW3.2
unnamed: D4.2 (A), SW4.2
unnamed: D5.2 (A), SW5.2
unnamed: D6.2 (A), SW6.2
unnamed: D7.2 (A), SW7.2
unnamed: D8.2 (A), SW8.2
unnamed: D9.2 (A), SW9.2
unnamed: D10.2 (A), SW0.2
unnamed: D'1.2 (A), SW'1.2
unnamed: D,1.2 (A), SW,1.2
unnamed: D-1.2 (A), SW-1.2
unnamed: D.1.2 (A), SW.1.2
unnamed: D/1.2 (A), SW/1.2
unnamed: D;1.2 (A), SW;1.2
unnamed: D=1.2 (A), SW=1.2
unnamed: DA1.2 (A), SWA1.2
unnamed: DB1.2 (A), SWB1.2
unnamed: DBACK1.2 (A), SWBACK1.2
unnamed: DC1.2 (A), SWC1.2
unnamed: DCAPS1.2 (A), SWCAPS1.2
unnamed: DD1.2 (A), SWD1.2
unnamed: DDEL1.2 (A), SWDEL1.2
unnamed: DDOWN1.2 (A), SWDOWN1.2
unnamed: DE1.2 (A), SWE1.2
unnamed: DENTER1.2 (A), SWENTER1.2
unnamed: DESC1.2 (A), SWESC1.2
unnamed: DF1.2 (A), SWF1.2
unnamed: DG1.2 (A), SWG1.2
unnamed: DH1.2 (A), SWH1.2
unnamed: DI1.2 (A), SWI1.2
unnamed: DINS1.2 (A), SWINS1.2
unnamed: DJ1.2 (A), SWJ1.2
unnamed: DK1.2 (A), SWK1.2
unnamed: DL1.2 (A), SWL1.2
unnamed: DLALT1.2 (A), SWLALT1.2
unnamed: DLCTRL1.2 (A), SWLCTRL1.2
unnamed: DLEFT1.2 (A), SWLEFT1.2
unnamed: DLSHIFT1.2 (A), SWLSHIFT1.2
unnamed: DLWIN1.2 (A), SWLWIN1.2
unnamed: DM1.2 (A), SWM1.2
unnamed: DN1.2 (A), SWN1.2
unnamed: DO1.2 (A), SWO1.2
unnamed: DP1.2 (A), SWP1.2
unnamed: DPDN1.2 (A), SWPDN1.2
unnamed: DPUP1.2 (A), SWPUP1.2
unnamed: DQ1.2 (A), SWQ1.2
unnamed: DR1.2 (A), SWR1.2
unnamed: DRALT1.2 (A), SWRALT1.2
unnamed: DRCTRL1.2 (A), SWRCTRL1.2
unnamed: DRIGHT1.2 (A), SWRIGHT1.2
unnamed: DRSHIFT1.2 (A), SWRSHIFT1.2
unnamed: DRWIN1.2 (A), SWRWIN1.2
unnamed: DS1.2 (A), SWS1.2
unnamed: DSPACE1.2 (A), SWSPACE1.2
unnamed: DT1.2 (A), SWT1.2
unnamed: DTAB1.2 (A), SWTAB1.2
unnamed: DU1.2 (A), SWU1.2
unnamed: DUP1.2 (A), SWUP1.2
unnamed: DV1.2 (A), SWV1.2
unnamed: DW1.2 (A), SWW1.2
unnamed: DX1.2 (A), SWX1.2
unnamed: DY1.2 (A), SWY1.2
unnamed: DZ1.2 (A), SWZ1.2
unnamed: D[1.2 (A), SW[1.2
unnamed: D\1.2 (A), SW\1.2
unnamed: D]1.2 (A), SW]1.2
unnamed: LED0.2 (DIN), LED9.4 (DOUT)
unnamed: LED1.2 (DIN), LEDESC1.4 (DOUT)
unnamed: LED1.4 (DOUT), LED2.2 (DIN)
unnamed: LED2.4 (DOUT), LED3.2 (DIN)
unnamed: LED3.4 (DOUT), LED4.2 (DIN)
unnamed: LED4.4 (DOUT), LED5.2 (DIN)
unnamed: LED5.4 (DOUT), LED6.2 (DIN)
unnamed: LED6.4 (DOUT), LED7.2 (DIN)
unnamed: LED7.4 (DOUT), LED8.2 (DIN)
unnamed: LED8.4 (DOUT), LED9.2 (DIN)
unnamed: LED'1.2 (DIN), LED;1.4 (DOUT)
unnamed: LED'1.4 (DOUT), LEDENTER1.2 (DIN)
unnamed: LED,1.2 (DIN), LED.1.4 (DOUT)
unnamed: LED,1.4 (DOUT), LEDM1.2 (DIN)
unnamed: LED0.4 (DOUT), LED-1.2 (DIN)
unnamed: LED-1.4 (DOUT), LED=1.2 (DIN)
unnamed: LED.1.2 (DIN), LED/1.4 (DOUT)
unnamed: LED/1.2 (DIN), LEDRSHIFT1.4 (DOUT)
unnamed: LED;1.2 (DIN), LEDL1.4 (DOUT)
unnamed: LED=1.4 (DOUT), LEDBACK1.2 (DIN)
unnamed: LEDA1.2 (DIN), LEDCAPS1.4 (DOUT)
unnamed: LEDA1.4 (DOUT), LEDS1.2 (DIN)
unnamed: LEDB1.2 (DIN), LEDN1.4 (DOUT)
unnamed: LEDB1.4 (DOUT), LEDV1.2 (DIN)
unnamed: LEDBACK1.4 (DOUT), LEDDEL1.2 (DIN)
unnamed: LEDC1.2 (DIN), LEDV1.4 (DOUT)
unnamed: LEDC1.4 (DOUT), LEDX1.2 (DIN)
unnamed: LEDCAPS1.2 (DIN), LEDTAB1.4 (DOUT)
unnamed: LEDD1.2 (DIN), LEDS1.4 (DOUT)
unnamed: LEDD1.4 (DOUT), LEDF1.2 (DIN)
unnamed: LEDDEL1.4 (DOUT), LEDINS1.2 (DIN)
unnamed: LEDDOWN1.2 (DIN), LEDLEFT1.4 (DOUT)
unnamed: LEDDOWN1.4 (DOUT), LEDRIGHT1.2 (DIN)
unnamed: LEDE1.2 (DIN), LEDR1.4 (DOUT)
unnamed: LEDE1.4 (DOUT), LEDW1.2 (DIN)
unnamed: LEDENTER1.4 (DOUT), LEDPUP1.2 (DIN)
unnamed: LEDF1.4 (DOUT), LEDG1.2 (DIN)
unnamed: LEDG1.4 (DOUT), LEDH1.2 (DIN)
unnamed: LEDH1.4 (DOUT), LEDJ1.2 (DIN)
unnamed: LEDI1.2 (DIN), LEDO1.4 (DOUT)
unnamed: LEDI1.4 (DOUT), LEDU1.2 (DIN)
unnamed: LEDINS1.4 (DOUT), LED\1.2 (DIN)
unnamed: LEDJ1.4 (DOUT), LEDK1.2 (DIN)
unnamed: LEDK1.4 (DOUT), LEDL1.2 (DIN)
unnamed: LEDLALT1.2 (DIN), LEDLWIN1.4 (DOUT)
unnamed: LEDLALT1.4 (DOUT), LEDSPACE1.2 (DIN)
unnamed: LEDLCTRL1.2 (DIN), LEDLSHIFT1.4 (DOUT)
unnamed: LEDLCTRL1.4 (DOUT), LEDLWIN1.2 (DIN)
unnamed: LEDLEFT1.2 (DIN), LEDRCTRL1.4 (DOUT)
unnamed: LEDLSHIFT1.2 (DIN), LEDZ1.4 (DOUT)
unnamed: LEDM1.4 (DOUT), LEDN1.2 (DIN)
unnamed: LEDO1.2 (DIN), LEDP1.4 (DOUT)
unnamed: LEDP1.2 (DIN), LED[1.4 (DOUT)
unnamed: LEDPDN1.2 (DIN), LEDPUP1.4 (DOUT)
unnamed: LEDPDN1.4 (DOUT), LEDUP1.2 (DIN)
unnamed: LEDQ1.2 (DIN), LEDW1.4 (DOUT)
unnamed: LEDQ1.4 (DOUT), LEDTAB1.2 (DIN)
unnamed: LEDR1.2 (DIN), LEDT1.4 (DOUT)
unnamed: LEDRALT1.2 (DIN), LEDSPACE1.4 (DOUT)
unnamed: LEDRALT1.4 (DOUT), LEDRWIN1.2 (DIN)
unnamed: LEDRCTRL1.2 (DIN), LEDRWIN1.4 (DOUT)
unnamed: LEDRSHIFT1.2 (DIN), LEDUP1.4 (DOUT)
unnamed: LEDT1.2 (DIN), LEDY1.4 (DOUT)
unnamed: LEDU1.4 (DOUT), LEDY1.2 (DIN)
unnamed: LEDX1.4 (DOUT), LEDZ1.2 (DIN)
unnamed: LED[1.2 (DIN), LED]1.4 (DOUT)
unnamed: LED\1.4 (DOUT), LED]1.2 (DIN)
VCC: A2.40 (VBUS), LED0.3 (VDD), LED1.3 (VDD), LED2.3 (VDD), LED3.3 (VDD), LED4.3 (VDD), LED5.3 (VDD), LED6.3 (VDD), LED7.3 (VDD), LED8.3 (VDD), LED9.3 (VDD), LED'1.3 (VDD), LED,1.3 (VDD), LED-1.3 (VDD), LED.1.3 (VDD), LED/1.3 (VDD), LED;1.3 (VDD), LED=1.3 (VDD), LEDA1.3 (VDD), LEDB1.3 (VDD), LEDBACK1.3 (VDD), LEDC1.3 (VDD), LEDCAPS1.3 (VDD), LEDD1.3 (VDD), LEDDEL1.3 (VDD), LEDDOWN1.3 (VDD), LEDE1.3 (VDD), LEDENTER1.3 (VDD), LEDESC1.3 (VDD), LEDF1.3 (VDD), LEDG1.3 (VDD), LEDH1.3 (VDD), LEDI1.3 (VDD), LEDINS1.3 (VDD), LEDJ1.3 (VDD), LEDK1.3 (VDD), LEDL1.3 (VDD), LEDLALT1.3 (VDD), LEDLCTRL1.3 (VDD), LEDLEFT1.3 (VDD), LEDLSHIFT1.3 (VDD), LEDLWIN1.3 (VDD), LEDM1.3 (VDD), LEDN1.3 (VDD), LEDO1.3 (VDD), LEDP1.3 (VDD), LEDPDN1.3 (VDD), LEDPUP1.3 (VDD), LEDQ1.3 (VDD), LEDR1.3 (VDD), LEDRALT1.3 (VDD), LEDRCTRL1.3 (VDD), LEDRIGHT1.3 (VDD), LEDRSHIFT1.3 (VDD), LEDRWIN1.3 (VDD), LEDS1.3 (VDD), LEDSPACE1.3 (VDD), LEDT1.3 (VDD), LEDTAB1.3 (VDD), LEDU1.3 (VDD), LEDUP1.3 (VDD), LEDV1.3 (VDD), LEDW1.3 (VDD), LEDX1.3 (VDD), LEDY1.3 (VDD), LEDZ1.3 (VDD), LED[1.3 (VDD), LED\1.3 (VDD), LED]1.3 (VDD)

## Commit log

2026-07-25 Started Schematic containing only keyboard
    [65ROL-PCB.kicad_pcb, 65ROL-PCB.kicad_sch]
2026-07-25 Finished basic key schematic and linked footprints
    [65ROL-PCB.kicad_sch, BoardKeys.kicad_sch, MainBoardKeys.kicad_sch]
2026-07-26 Placed all switches on main PCB
    [65ROL-PCB.kicad_pcb, BoardKeys.kicad_sch]
2026-07-26 Placed all diodes and made edge
    [65ROL-PCB.kicad_pcb, 65ROL-PCB.kicad_sch]
2026-07-26 Routed keyboard and made ground fill
    [65ROL-PCB.kicad_pcb]
2026-07-27 Update README with Devlog 2 details and images
    Added details about the key layout and PCB design process in Devlog 2.
2026-07-27 Update README with Devlog 3 details
    Added details about the progress and challenges faced in Devlog 3, including diode placement, board outlines, and future plans.
2026-08-03 Added LEDs to schematic and PCB
    [65ROL-PCB.kicad_pcb, 65ROL-PCB.kicad_sch, BoardLEDs.kicad_sch]
2026-08-05 Update README with Devlog 4 details
    Added details about Devlog 4, including schematic and routing challenges with LEDs.
2026-08-15 Update README with BOM and Devlog 5 details
    Added Bill of Materials (BOM) and updates from Devlog 5 regarding LED components and design changes.
2026-08-17 Added Scematic for rear extention and LED logic shifter, decoupling capacitors and data line resitors
    [65ROL-PCB.kicad_sch, BoardLEDs.kicad_sch, RearExtension.kicad_sch]
2026-08-18 Refactored PCB Folder and Created 2nd project
    [65ROL-PCB.kicad_sch, BoardKeys.kicad_sch, BoardLEDs.kicad_sch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]
2026-08-18 Added all CAD models for Keyboard PCB and exported
    [Keycap.STEP, MX_Switch.STEP, SN74AHCT1G125DCKT.step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]
2026-08-21 Finished Rear Extention and added 3D Models
    [OLED Screen.STEP, RearExtensionPCB.kicad_pcb, RearExtensionPCB.kicad_sch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]
2026-08-22 Devlog 9
    Documented progress on PCB routing and case design.
2026-08-22 Updated Case cad
    [CaseLeft.3mf, CaseRight.3mf, RearExtensionPCB.kicad_pcb]
